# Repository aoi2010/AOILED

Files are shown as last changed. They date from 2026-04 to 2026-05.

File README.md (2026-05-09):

# AOILED
A WLED(Audio Reactive) Based LED Strips Controller for 12v LED Strips

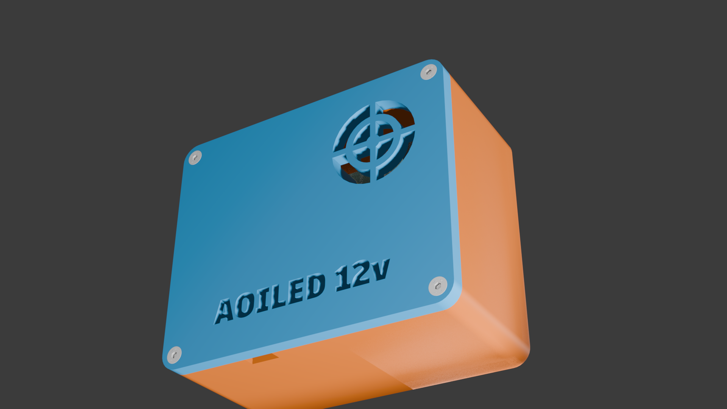
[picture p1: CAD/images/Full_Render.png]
Render


### Inspiration

I wanted to create a LED strip controller that could be used to control 12v WS2811 LED strips. It also supports audio based effects using WLED'S Audio Reactive Mode. I wanted to use and test the WLED Firmware also.

### Challenges

Believe it or not, this was my third time using Fusion 360 and KiCad! I watched numerous tutorials and guides and did a lot of googling, but in the end, I'm pretty proud of the final product. I had the most struggle figuring out the tolerances and dimensions. Also in KiCad, I had a lot of trouble with footprints and making sure everything was aligned properly and the traces were correct(but it became a little long traces and some may not look good).

### How To Use This
- STEP 1: Buy all the things listed in the BOM, print the case and also order the PCB.
- STEP 2: Flash [WLED](https://kno.wled.ge/) to the XIAO.
- STEP 3: Solder the components to the PCB and assemble the case.
- STEP 4: Use a 12v DC Power Supply to power the PCB and connect the LED strip to the PCB via the JST-XH connectors i.e. one end to the PCB and solder it and the other to the LED strip via its JST-XH connector.
- STEP 5: Install the WLED App on your phone and connect to the WLED Network(WLED-AP) and configure it to connect to your WiFi Network and change the type of LEDs in the settings.
- STEP 6: Do Anything With It and have fun!
Thank You! Also Please give a star to this poor fellow if you like the project. Thank You Again!

### Specifications

BOM (from `BOM.csv`):
###### Some of the products in the BOM are more than required because Robu doesnot allow products to be bought under Rs. 10. Thank You For Understanding.

| Name | Qty | Purpose | Cost (USD) | Link | Distributor |
|---|---:|---|---:|---|---|
| JST SM 3pin Male | 1 | For connecting the LED Strips | $0.08 | [Buy](https://quartzcomponents.com/products/jst-sm-3-pin-connector-male) | Quartz Components |
| JST SM 3pin Female | 1 | For connecting the LED Strips | $0.08 | [Buy](https://quartzcomponents.com/products/jst-sm-3-pin-2517-2518-connector-male-female-1-pair) | Quartz Components |
| 24AWG High Voltage Silicone Wire 3000V - Red | 1 | Connecting the INMP441 to the PCB | $0.20 | [Buy](https://robu.in/product/24awg-high-voltage-silicone-wire-3000v-red/) | Robu |
| PCB | 1 | 2-layers PCB | $11.85 | [Buy](https://jlcpcb.com) | JLCPCB |
| 3d Printing of Case Shipping | 1 | For the Case Shipping Charges by Souptik Samanta | $3.25 | [Reference](https://app.slack.com/client/E09V59WQY1E/C095YP8GLKT) | Souptik Samanta via Printing Legion |
| WS2811 Neopixel LED Strip 60LED/MTR - 12V Addressable LED Strip (5 Meter Pack) | 1 | LED | $6.60 | [Buy](https://quartzcomponents.com/products/led-strip-ws2811-non-waterproof-60led-mtr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) | Quartz Components |
| 24AWG High Quality Ultra Flexible Silicone Wire - Yellow | 2 | Connecting the INMP441 to the PCB | $0.20 | [Buy](https://robu.in/product/high-quality-ultra-flexible-24awg-silicone-wire-yellow/) | Robu |
| 24AWG High Quality Ultra Flexible Silicone Wire - Blue | 2 | Connecting the INMP441 to the PCB | $0.20 | [Buy](https://robu.in/product/high-quality-ultra-flexible-24awg-silicone-wire-1000m-blue/) | Robu |
| M3 X 25mm Hex (Allen) CSK SS 304 Screw (Dia. 3mm, Length 25mm) | 4 | Screws | $0.15 | [Buy](https://onlyscrews.in/products/m3-x-25mm-hex-allen-csk-ss-304-screw?variant=49181133799737) | OnlyScrews |
| M3 X 6mm Brass Threaded Inserts (Dia. 3mm, Length 6mm) | 4 | Screws Inserts | $0.15 | [Buy](https://onlyscrews.in/products/m3-x-6mm-brass-threaded-inserts?variant=49418769203513) | OnlyScrews |
| SN74AHCT125N | 1 | Level Shifting of Data | $1.10 | [Buy](https://robu.in/product/sn74ahct125n-texas-instruments-8ma-1-4-5v5-5v-8ma-4-dip-14-buffers-drivers-receivers-transceivers-rohs/) | Robu |
| 68 ohms resistor | 44 | Resistance | $0.15 | [Buy](https://robu.in/product/68-ohm-0-25w-metal-film-resistor-pack-of-100/) | Robu |
| XIAO ESP32S3 | 1 | MCU | $9.90 | [Buy](https://robocraze.com/products/seeed-studio-xiao-esp32-s3-development-board-supports-wi-fi-bluetooth-5-0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) | RoboCraze |
| INMP441 I2S Microphone | 1 | For Audio | $2.10 | [Buy](https://robocraze.com/products/inmp441-mems-high-precision-omnidirectional-microphone-module-i2s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) | Robo Craze |
| 1n5822 Diode | 2 | Diode | $0.51 | [Buy](http://robu.in/product/1n5822-mdd-40v-525mv3a-3a-do-201ad-schottky-diodes-rohs/) | Robu |
| LM2596S-5.0 | 1 | Step Down Voltage | $0.73 | [Buy](https://robu.in/product/lm2596s-5-0-xblw-step-down-type-fixed-5v-to-263-5l-dc-dc-converters-rohs/) | Robu |
| SRR1208-330YL-BOURNS-2.8A 33uH ±15% 3.8A SMD, 12.7×12.7mm Power Inductor | 1 | 12v to 5v | $1.25 | [Buy](https://robu.in/product/srr1208-330yl-bourns-2-8a-33uh-%C2%B115-3-8a-smd12-7x12-7mm-power-inductors-rohs/) | Robu |
| Nichicon-220uF 50V | 2 | Decoupling | $0.50 | [Buy](https://robu.in/product/uhe1h221mpd-nichicon-220uf-50v-84m%cf%89100khz-%c2%b120-1-05a100khz-plugind10xl16mm-aluminum-electrolytic-capacitors-leaded-rohs/) | Robu |
| Nichicon 470uf 50v | 3 | Decoupling | $1.05 | [Buy](https://robu.in/product/uhe1h471mhd6-nichicon-470uf-50v-45m%cf%89100khz-%c2%b120-1-66a100khz-plugind12-5xl20mm-aluminum-electrolytic-capacitors-leaded-rohs/) | Robu |
| 100nf Disc Capacitor | 8 | Decoupling | $0.10 | [Buy](https://robu.in/product/100nf-50v-disc-capacitor/) | Robu |
| PJ-102A | 2 | 12v Power Input (QTY is 2 because minimum order quantity is 2) | $3.23 | [Buy](https://www.lioncircuits.com/parts/PJ-102A) | Lion Circuits |
| Shipping | 1 | Shipping Charges | $1.32 | N/A | Shipping Charges |
| TAX | 1 | Tax | $1.30 | N/A | Indian Govt. |

Others:
- WLED Firmware
- PCB Gerber Files
- Case STL files for 3D printing

Schematic | PCB Layout |
:-------------------------:|:-------------------------:|
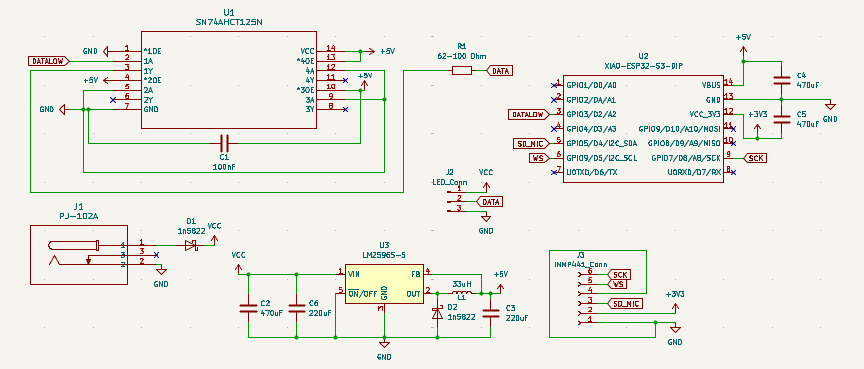
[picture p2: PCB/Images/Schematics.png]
Schematic
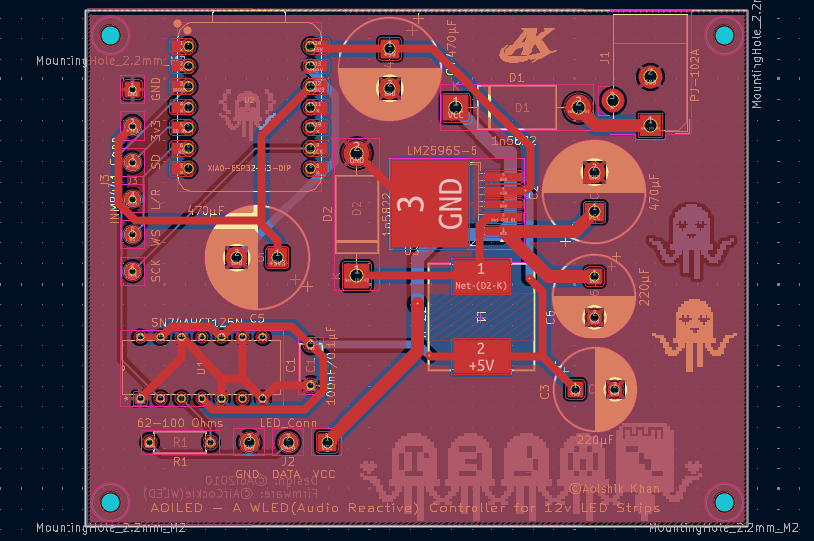
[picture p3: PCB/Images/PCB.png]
PCB Layout
 |  |

 Case Top | Case Bottom |
:-------------------------:|:-------------------------:|
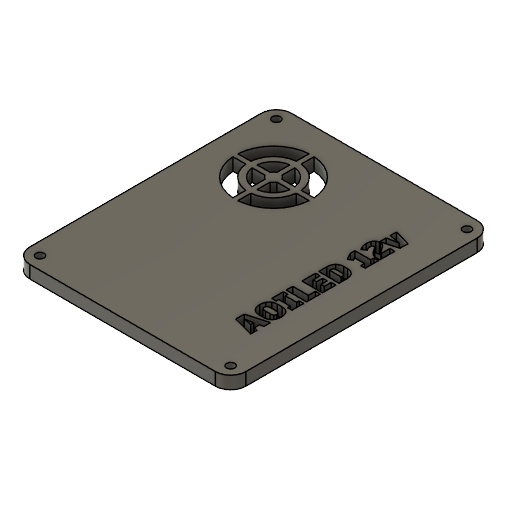
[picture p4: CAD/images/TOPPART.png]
Case Top
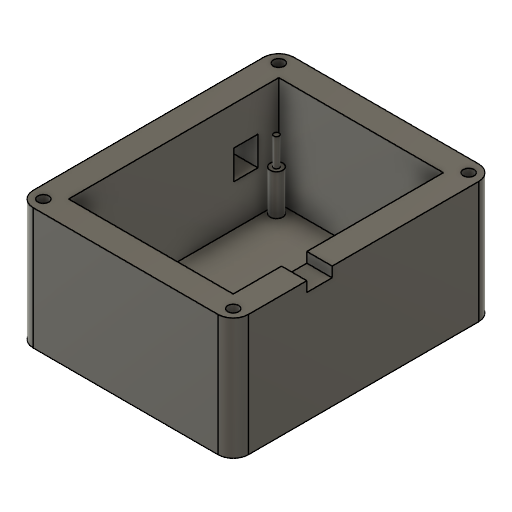
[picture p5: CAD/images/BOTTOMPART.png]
Case Bottom
  | 

 <div align="center">

Assembled Case | PCB VIEW |
:-------------------------:|:-------------------------:|
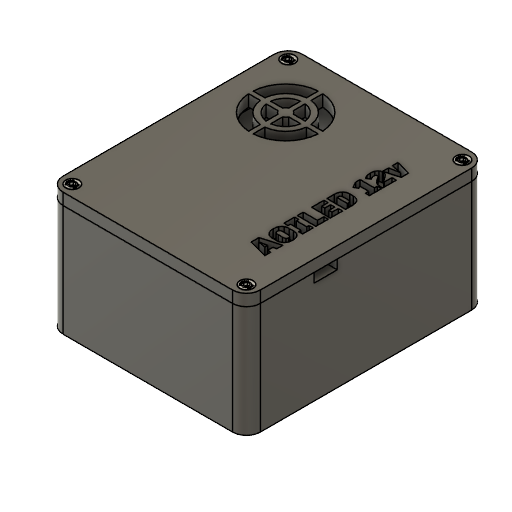
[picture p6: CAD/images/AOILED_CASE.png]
Assembled Case
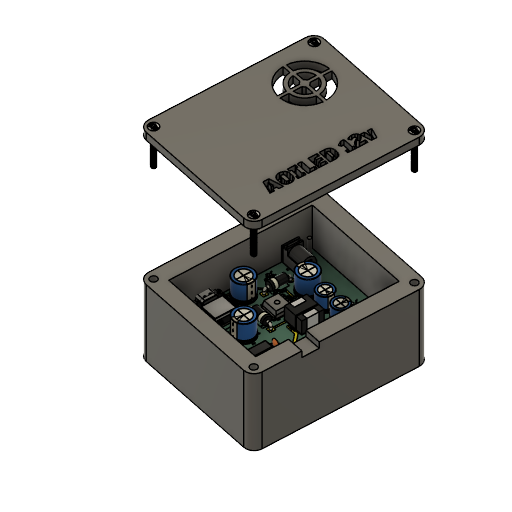
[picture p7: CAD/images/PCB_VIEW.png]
PCB VIEW
 |  |

###### Note: The XIAO is not meant to be connected by the user so it is inside the case and not available for the user to connect to. The user can flash the firmware to the XIAO before assembling the case and then assemble the case and use it.
</div>

### Notes
The firmeare I used is WLED. It is a premade firmare by Aircoookie and it is open source. Here is the link to it: [Github](https://github.com/wled/WLED) | [Wiki](https://kno.wled.ge/) | [Flasher(Official)](https://install.wled.me/) | [Flasher(Third Party)](https://wled-install.github.io/)

Thank You for Understanding.
<div align="center">

## Thanks For Reading! Also leave a star if you like the project! ⭐

</div>

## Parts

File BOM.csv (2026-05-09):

Name | Purpose | Quantity | Total Cost (USD) | Link | Distributor
JST SM 3pin Male | For connecting the LED Strips | 1 | 0.08 | https://quartzcomponents.com/products/jst-sm-3-pin-connector-male | Quartz Components
JST SM 3pin Female | For connecting the LED Strips | 1 | 0.08 | https://quartzcomponents.com/products/jst-sm-3-pin-2517-2518-connector-male-female-1-pair | Quartz Components
24AWG High Voltage Silicone Wire 3000V – Red | Connecting the INMP441 to the PCB | 1 | 0.20 | https://robu.in/product/24awg-high-voltage-silicone-wire-3000v-red/ | Robu
PCB | 2-layers PCB | 1 | 11.85 | https://jlcpcb.com | JLCPCB
3d Printing of Case Shipping | For the Case Shipping Charges by Souptik Samanta | 1 | 3.25 | https://app.slack.com/client/E09V59WQY1E/C095YP8GLKT | Souptik Samanta via Printing Legion
WS2811 Neopixel LED Strip 60LED/MTR - 12V Addressable LED Strip (5 Meter Pack) | LED | 1 | 6.60 | https://quartzcomponents.com/products/led-strip-ws2811-non-waterproof-60led-mtr?variant=43998632804586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 | Quartz Components
24AWG High Quality Ultra Flexible Silicone Wire – Yellow | Connecting the INMP441 to the PCB | 2 | 0.20 | https://robu.in/product/high-quality-ultra-flexible-24awg-silicone-wire-yellow/ | Robu
24AWG High Quality Ultra Flexible Silicone Wire – Blue | Connecting the INMP441 to the PCB | 2 | 0.20 | https://robu.in/product/high-quality-ultra-flexible-24awg-silicone-wire-1000m-blue/ | Robu
M3 X 25mm Hex (Allen) CSK SS 304 Screw (Dia. 3mm, Length 25mm) | Screws | 4 | 0.15 | https://onlyscrews.in/products/m3-x-25mm-hex-allen-csk-ss-304-screw?variant=49181133799737 | OnlyScrews
M3 X 6mm Brass Threaded Inserts (Dia. 3mm, Length 6mm) | Screws Inserts | 4 | 0.15 | https://onlyscrews.in/products/m3-x-6mm-brass-threaded-inserts?variant=49418769203513 | OnlyScrews
SN74AHCT125N | Level Shifting of Data | 1 | 1.10 | https://robu.in/product/sn74ahct125n-texas-instruments-8ma-1-4-5v5-5v-8ma-4-dip-14-buffers-drivers-receivers-transceivers-rohs/ | Robu
68 ohms resistor | Resistance | 44 | 0.15 | https://robu.in/product/68-ohm-0-25w-metal-film-resistor-pack-of-100/ | Robu
XIAO ESP32S3 | MCU | 1 | 9.90 | https://robocraze.com/products/seeed-studio-xiao-esp32-s3-development-board-supports-wi-fi-bluetooth-5-0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 | RoboCraze
INMP441 I2S Microphone | For Audio | 1 | 2.10 | https://robocraze.com/products/inmp441-mems-high-precision-omnidirectional-microphone-module-i2s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 | Robo Craze
1n5822 Diode | Diode | 2 | 0.51 | http://robu.in/product/1n5822-mdd-40v-525mv3a-3a-do-201ad-schottky-diodes-rohs/ | Robu
LM2596S-5.0 | Step Down Voltage | 1 | 0.73 | https://robu.in/product/lm2596s-5-0-xblw-step-down-type-fixed-5v-to-263-5l-dc-dc-converters-rohs/ | Robu
SRR1208-330YL-BOURNS-2.8A 33uH ±15% 3.8A SMD,12.7×12.7mm Power Inductor | 12v to 5v | 1 | 1.25 | https://robu.in/product/srr1208-330yl-bourns-2-8a-33uh-%C2%B115-3-8a-smd12-7x12-7mm-power-inductors-rohs/ | Robu
Nichicon-220uF 50V | Decoupling | 2 | 0.50 | https://robu.in/product/uhe1h221mpd-nichicon-220uf-50v-84m%cf%89100khz-%c2%b120-1-05a100khz-plugind10xl16mm-aluminum-electrolytic-capacitors-leaded-rohs/ | Robu
Nichicon 470uf 50v | Decoupling | 3 | 1.05 | https://robu.in/product/uhe1h471mhd6-nichicon-470uf-50v-45m%cf%89100khz-%c2%b120-1-66a100khz-plugind12-5xl20mm-aluminum-electrolytic-capacitors-leaded-rohs/ | Robu
100nf Disc Capacitor | Decoupling | 8 | 0.10 | https://robu.in/product/100nf-50v-disc-capacitor/ | Robu
PJ-102A | 12v Power Input(QTY is 2 cuz min order qty is 2) | 2 | 3.23 | https://www.lioncircuits.com/parts/PJ-102A | Lion Circuits
Shipping | Shipping Charges | 1 | 1.32 | N/A | Shipping Charges
TAX | Tax | 1 | 1.30 | N/A | Indian Govt.

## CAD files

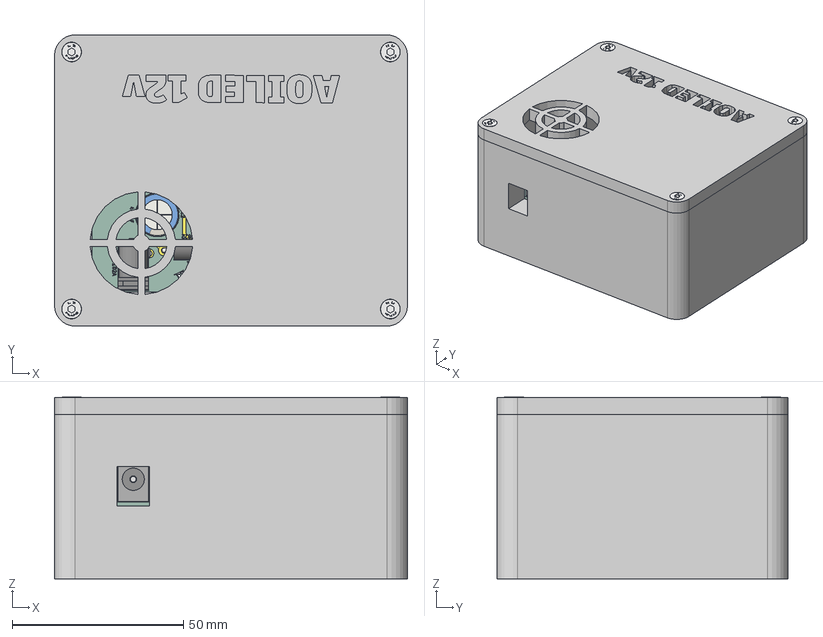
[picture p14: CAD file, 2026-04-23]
CAD/AOILED_CASE.step
103.0 x 85.0 x 53.1 mm
CSK M3 x 4

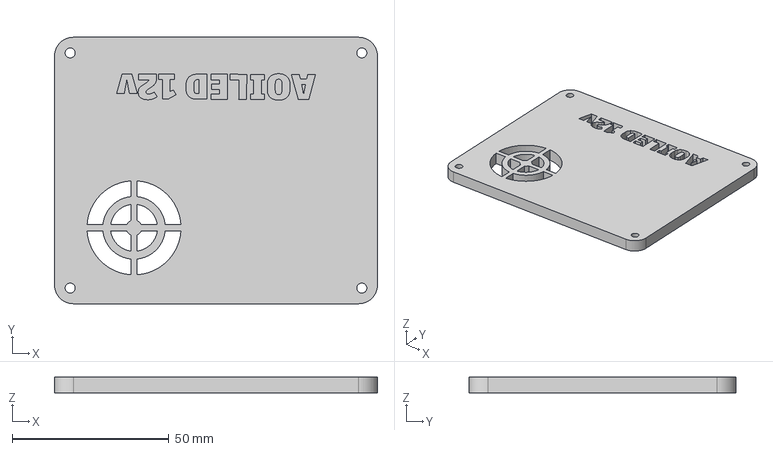
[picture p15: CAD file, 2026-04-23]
CAD/SEPARATE/TOPPART.step
103.0 x 85.0 x 5.00 mm

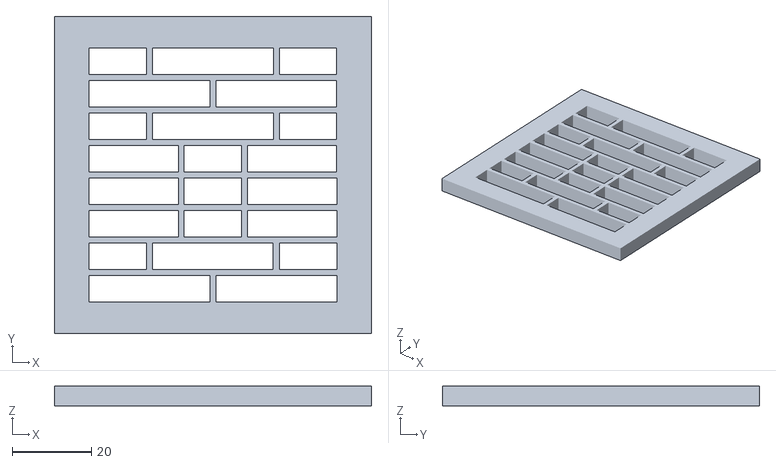
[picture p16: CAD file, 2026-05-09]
Firmware/WLED-0.15.3/usermods/word-clock-matrix/Word Clock Baffle.stl
80.0 x 80.0 x 5.00

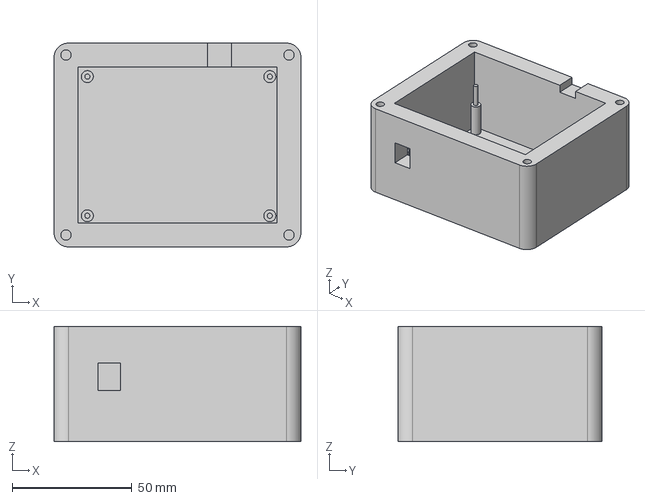
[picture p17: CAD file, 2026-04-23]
CAD/SEPARATE/BOTTOMPART.step
103.0 x 85.0 x 48.0 mm

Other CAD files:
CAD/stl_files/TOPPART.stl
CAD/stl_files/BOTTOMPART.stl
CAD/AOILED_CASE.f3z

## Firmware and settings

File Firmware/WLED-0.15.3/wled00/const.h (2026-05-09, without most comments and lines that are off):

#define WLED_CONST_H
#define GRADIENT_PALETTE_COUNT 58
  #define WLED_BRAND "WLED"
  #define WLED_PRODUCT_NAME "FOSS"
#define DEFAULT_CLIENT_SSID "Your_Network"
#define DEFAULT_AP_SSID     WLED_BRAND "-AP"
#define DEFAULT_AP_PASS     "wled1234"
#define DEFAULT_OTA_PASS    "wledota"
#define DEFAULT_MDNS_NAME   "x"
  #define WLED_MAX_WIFI_COUNT 3
  #if defined(ESP8266) || defined(CONFIG_IDF_TARGET_ESP32S2)
    #define WLED_MAX_USERMODS 4
  #else
    #define WLED_MAX_USERMODS 6
  #endif
  #ifdef ESP8266
    #define WLED_MAX_DIGITAL_CHANNELS 3
    #define WLED_MAX_ANALOG_CHANNELS 5
    #define WLED_MAX_BUSSES 4                 // will allow 3 digital & 1 analog RGB
    #define WLED_MIN_VIRTUAL_BUSSES 3
  #else
    #define WLED_MAX_ANALOG_CHANNELS (LEDC_CHANNEL_MAX*LEDC_SPEED_MODE_MAX)
    #if defined(CONFIG_IDF_TARGET_ESP32C3)    // 2 RMT, 6 LEDC, only has 1 I2S but NPB does not support it ATM
      #define WLED_MAX_BUSSES 6               // will allow 2 digital & 2 analog RGB or 6 PWM white
      #define WLED_MAX_DIGITAL_CHANNELS 2
      #define WLED_MIN_VIRTUAL_BUSSES 4
    #elif defined(CONFIG_IDF_TARGET_ESP32S2)  // 4 RMT, 8 LEDC, only has 1 I2S bus, supported in NPB
      #define WLED_MAX_BUSSES 14              // will allow 12 digital & 2 analog RGB
      #define WLED_MAX_DIGITAL_CHANNELS 12    // x4 RMT + x1/x8 I2S0
      #define WLED_MIN_VIRTUAL_BUSSES 4
    #elif defined(CONFIG_IDF_TARGET_ESP32S3)  // 4 RMT, 8 LEDC, has 2 I2S but NPB supports parallel x8 LCD on I2S1
      #define WLED_MAX_BUSSES 14              // will allow 12 digital & 2 analog RGB
      #define WLED_MAX_DIGITAL_CHANNELS 12    // x4 RMT + x8 I2S-LCD
      #define WLED_MIN_VIRTUAL_BUSSES 6
    #else
      #define WLED_MAX_BUSSES 19              // will allow 16 digital & 3 analog RGB
      #define WLED_MAX_DIGITAL_CHANNELS 16    // x1/x8 I2S1 + x8 RMT
      #define WLED_MIN_VIRTUAL_BUSSES 6
    #endif
  #endif
  #ifdef ESP8266
    #define WLED_MAX_BUTTONS 2
  #else
    #define WLED_MAX_BUTTONS 4
  #endif
#if defined(ESP8266) || defined(CONFIG_IDF_TARGET_ESP32S2)
#define WLED_MAX_COLOR_ORDER_MAPPINGS 5
#else
#define WLED_MAX_COLOR_ORDER_MAPPINGS 10
#endif
#if defined(WLED_MAX_LEDMAPS) && (WLED_MAX_LEDMAPS > 32 || WLED_MAX_LEDMAPS < 10)
  #undef WLED_MAX_LEDMAPS
#endif
#ifndef WLED_MAX_LEDMAPS
  #if defined(ESP8266) || defined(CONFIG_IDF_TARGET_ESP32S2)
    #define WLED_MAX_LEDMAPS 10
  #else
    #define WLED_MAX_LEDMAPS 16
  #endif
#endif
  #ifdef ESP8266
    #define WLED_MAX_SEGNAME_LEN 32
  #else
    #define WLED_MAX_SEGNAME_LEN 64
  #endif
#define USERMOD_ID_RESERVED               0     //Unused. Might indicate no usermod present
#define USERMOD_ID_UNSPECIFIED            1     //Default value for a general user mod that does not specify a custom ID
#define USERMOD_ID_EXAMPLE                2     //Usermod "usermod_v2_example.h"
#define USERMOD_ID_TEMPERATURE            3     //Usermod "usermod_temperature.h"
#define USERMOD_ID_FIXNETSERVICES         4     //Usermod "usermod_Fix_unreachable_netservices.h"
#define USERMOD_ID_PIRSWITCH              5     //Usermod "usermod_PIR_sensor_switch.h"
#define USERMOD_ID_IMU                    6     //Usermod "usermod_mpu6050_imu.h"
#define USERMOD_ID_FOUR_LINE_DISP         7     //Usermod "usermod_v2_four_line_display.h
#define USERMOD_ID_ROTARY_ENC_UI          8     //Usermod "usermod_v2_rotary_encoder_ui.h"
#define USERMOD_ID_AUTO_SAVE              9     //Usermod "usermod_v2_auto_save.h"
#define USERMOD_ID_DHT                   10     //Usermod "usermod_dht.h"
#define USERMOD_ID_MODE_SORT             11     //Usermod "usermod_v2_mode_sort.h"
#define USERMOD_ID_VL53L0X               12     //Usermod "usermod_vl53l0x_gestures.h"
#define USERMOD_ID_MULTI_RELAY           13     //Usermod "usermod_multi_relay.h"
#define USERMOD_ID_ANIMATED_STAIRCASE    14     //Usermod "Animated_Staircase.h"
#define USERMOD_ID_RTC                   15     //Usermod "usermod_rtc.h"
#define USERMOD_ID_ELEKSTUBE_IPS         16     //Usermod "usermod_elekstube_ips.h"
#define USERMOD_ID_SN_PHOTORESISTOR      17     //Usermod "usermod_sn_photoresistor.h"
#define USERMOD_ID_BATTERY               18     //Usermod "usermod_v2_battery.h"
#define USERMOD_ID_PWM_FAN               19     //Usermod "usermod_PWM_fan.h"
#define USERMOD_ID_BH1750                20     //Usermod "usermod_bh1750.h"
#define USERMOD_ID_SEVEN_SEGMENT_DISPLAY 21     //Usermod "usermod_v2_seven_segment_display.h"
#define USERMOD_RGB_ROTARY_ENCODER       22     //Usermod "rgb-rotary-encoder.h"
#define USERMOD_ID_QUINLED_AN_PENTA      23     //Usermod "quinled-an-penta.h"
#define USERMOD_ID_SSDR                  24     //Usermod "usermod_v2_seven_segment_display_reloaded.h"
#define USERMOD_ID_CRONIXIE              25     //Usermod "usermod_cronixie.h"
#define USERMOD_ID_WIZLIGHTS             26     //Usermod "wizlights.h"
#define USERMOD_ID_WORDCLOCK             27     //Usermod "usermod_v2_word_clock.h"
#define USERMOD_ID_MY9291                28     //Usermod "usermod_MY9291.h"
#define USERMOD_ID_SI7021_MQTT_HA        29     //Usermod "usermod_si7021_mqtt_ha.h"
#define USERMOD_ID_BME280                30     //Usermod "usermod_bme280.h
#define USERMOD_ID_SMARTNEST             31     //Usermod "usermod_smartnest.h"
#define USERMOD_ID_AUDIOREACTIVE         32     //Usermod "audioreactive.h"
#define USERMOD_ID_ANALOG_CLOCK          33     //Usermod "Analog_Clock.h"
#define USERMOD_ID_PING_PONG_CLOCK       34     //Usermod "usermod_v2_ping_pong_clock.h"
#define USERMOD_ID_ADS1115               35     //Usermod "usermod_ads1115.h"
#define USERMOD_ID_BOBLIGHT              36     //Usermod "boblight.h"
#define USERMOD_ID_SD_CARD               37     //Usermod "usermod_sd_card.h"
#define USERMOD_ID_PWM_OUTPUTS           38     //Usermod "usermod_pwm_outputs.h
#define USERMOD_ID_SHT                   39     //Usermod "usermod_sht.h
#define USERMOD_ID_KLIPPER               40     //Usermod Klipper percentage
#define USERMOD_ID_WIREGUARD             41     //Usermod "wireguard.h"
#define USERMOD_ID_INTERNAL_TEMPERATURE  42     //Usermod "usermod_internal_temperature.h"
#define USERMOD_ID_LDR_DUSK_DAWN         43     //Usermod "usermod_LDR_Dusk_Dawn_v2.h"
#define USERMOD_ID_STAIRWAY_WIPE         44     //Usermod "stairway-wipe-usermod-v2.h"
#define USERMOD_ID_ANIMARTRIX            45     //Usermod "usermod_v2_animartrix.h"
#define USERMOD_ID_HTTP_PULL_LIGHT_CONTROL 46   //usermod "usermod_v2_HttpPullLightControl.h"
#define USERMOD_ID_TETRISAI              47     //Usermod "usermod_v2_tetris.h"
#define USERMOD_ID_MAX17048              48     //Usermod "usermod_max17048.h"
#define USERMOD_ID_BME68X                49     //Usermod "usermod_bme68x.h
#define USERMOD_ID_INA226                50     //Usermod "usermod_ina226.h"
#define USERMOD_ID_AHT10                 51     //Usermod "usermod_aht10.h"
#define USERMOD_ID_LD2410                52     //Usermod "usermod_ld2410.h"
#define USERMOD_ID_POV_DISPLAY           53     //Usermod "usermod_pov_display.h"
#define USERMOD_ID_PIXELS_DICE_TRAY      54     //Usermod "pixels_dice_tray.h"
#define AP_BEHAVIOR_BOOT_NO_CONN          0     //Open AP when no connection after boot
#define AP_BEHAVIOR_NO_CONN               1     //Open when no connection (either after boot or if connection is lost)
#define AP_BEHAVIOR_ALWAYS                2     //Always open
#define AP_BEHAVIOR_BUTTON_ONLY           3     //Only when button pressed for 6 sec
#define AP_BEHAVIOR_TEMPORARY             4     //Open AP when no connection after boot but only temporary
  #define WLED_AP_TIMEOUT            300000     //Temporary AP timeout
#define CALL_MODE_INIT           0     //no updates on init, can be used to disable updates
#define CALL_MODE_DIRECT_CHANGE  1
#define CALL_MODE_BUTTON         2     //default button actions applied to selected segments
#define CALL_MODE_NOTIFICATION   3     //caused by incoming notification (UDP or DMX preset)
#define CALL_MODE_NIGHTLIGHT     4     //nightlight progress
#define CALL_MODE_NO_NOTIFY      5     //change state but do not send notifications (UDP)
#define CALL_MODE_FX_CHANGED     6     //no longer used
#define CALL_MODE_HUE            7
#define CALL_MODE_PRESET_CYCLE   8     //no longer used
#define CALL_MODE_BLYNK          9     //no longer used
#define CALL_MODE_ALEXA         10
#define CALL_MODE_WS_SEND       11     //special call mode, not for notifier, updates websocket only
#define CALL_MODE_BUTTON_PRESET 12     //button/IR JSON preset/macro
#define RGBW_MODE_MANUAL_ONLY     0    // No automatic white channel calculation. Manual white channel slider
#define RGBW_MODE_AUTO_BRIGHTER   1    // New algorithm. Adds as much white as the darkest RGBW channel
#define RGBW_MODE_AUTO_ACCURATE   2    // New algorithm. Adds as much white as the darkest RGBW channel and subtracts this amount from each RGB channel
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

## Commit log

2026-04-17 Add LEDCONTROL KiCad project files
    Add a new KiCad project for the LEDCONTROL board: LEDCONTROL.kicad_sch (schematic), LEDCONTROL.kicad_pcb (PCB layout), LEDCONTROL.kicad_pro (project file) and an exported LEDCONTROL.zip.
    [LEDCONTROL.kicad_pcb, LEDCONTROL.kicad_sch]
2026-04-17 Add BOM.csv
    Add Bill Of Materials
    [BOM.csv]
2026-04-23 Add CAD files and Firmware
    [AOILED_CASE.f3z, AOILED_CASE.step, BOM.csv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]
2026-04-23 Expand README with project details and BOM
    Made The Readme
2026-04-26 Update README with BOM note and firmware link correction
    Added a note about product quantity requirements in BOM and corrected a typo in the firmware section.
2026-05-09 Look into the Inside of the Case, Update Firmware and BOM.
    Add the required components.
    [AutoCubeMap.xlsx, BOM.csv, IR_Remote_Codes.xlsx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]
